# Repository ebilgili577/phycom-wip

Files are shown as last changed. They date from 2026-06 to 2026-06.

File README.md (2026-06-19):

# Reaction Game

Final game

A two-player reaction game built on an Adafruit Feather M4 Express.
A central NeoPixel ring flashes a colour and players race to press the matching
button before a time window closes. The window shrinks after every round.

## Game modes

On boot you land on a **mode-select** screen: the ring shows a constant colour for the selected game,
the **MODE** button cycles between games, and **START** confirms and launches.

### Game 1 — Reaction
The ring flashes a colour and each player races their own clock to hit the match.
Each player has 3 lives. The window shrinks each round; first to 0 lives loses.

### Game 2 — Duel
Turn-based sudden death. The active player's HP LEDs light to show whose turn it
is (randomized), and they must hit the colour shown on the ring. A correct press passes the
turn and shrinks the window; a wrong press **or** a timeout loses the game.

More game modes can be added.

## Controls

From either game-over screen: **START** replays the same game, **MODE** returns
to the mode selector.

## Hardware

- [Bills of material (BOM)](docs/bills_of_material.svg)
- [Schematic](docs/schematic.svg)
- [Parts to assemble](docs/parts_to_assemble.svg)
- [Laser-cut chassis](design/laser_cut.svg)
- [3D-printed button caps](design/Button_print.scad) (OpenSCAD)

## Assembly

1. Gather parts from the [BOM](docs/bills_of_material.svg).
2. Laser-cut the chassis from [design/laser_cut.svg](design/laser_cut.svg).
3. 3D-print ten button caps from [design/Button_print.scad](design/Button_print.scad).
4. Wire the board following the [schematic](docs/schematic.svg) and [parts](docs/parts_to_assemble.svg).
5. Mount buttons, buzzers, HP LEDs, and the NeoPixel ring into the chassis and solder connections.
6. Upload the game and test.
7. Have fun!

## Software setup

1. Install the [Arduino IDE](https://www.arduino.cc/en/software).
2. Add board support for **Adafruit Feather M4 Express** via the [Adafruit board package](https://learn.adafruit.com/add-boards-arduino-ide).
3. Install libraries through the Library Manager:
   - [Adafruit NeoPixel](https://github.com/adafruit/Adafruit_NeoPixel)
   - [Bounce2](https://github.com/thomasfredericks/Bounce2)
4. Open `reaction_game.ino`, select **Adafruit Feather M4 Express**, and upload.

## Gallery

| Stage | Photo |
| --- | --- |
| Cardboard form-factor sketch | Cardboard prototype |
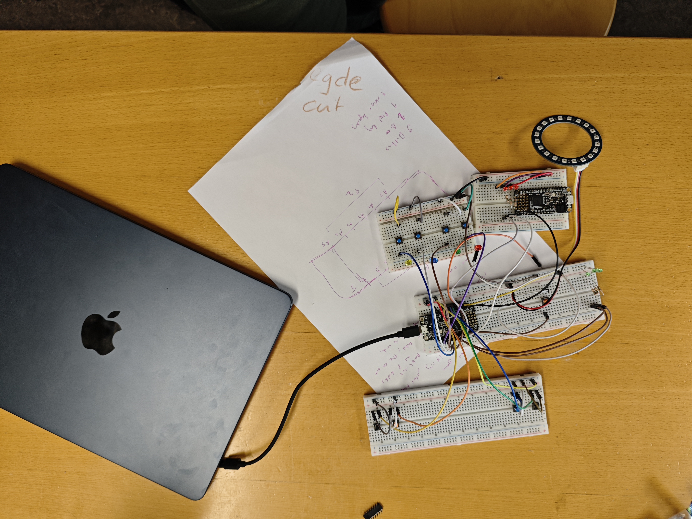
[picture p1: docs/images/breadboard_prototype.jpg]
Breadboard prototype
| Breadboard prototype |  |
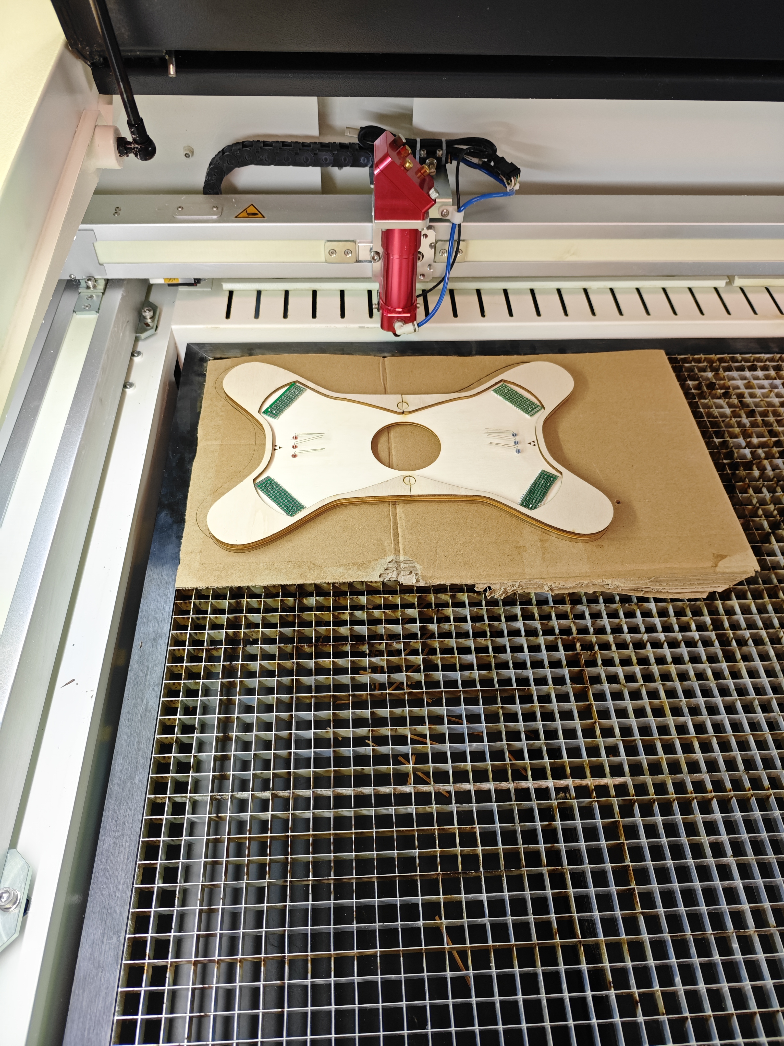
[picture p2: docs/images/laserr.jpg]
Laser cutting
| Laser-cutting the chassis |  |
| Final game | Final game |

## License

Licensed under the [MIT License](LICENSE).

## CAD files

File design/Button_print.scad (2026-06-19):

$fn = 36;
button_r = 3.35/2;

hole_r = 10/2;
h = 4;
little_h = 3;

button_travel = 0.3;

button_extra = 0.1;

hole_extra = 3/2;


// white one, good
module button_cover() {
    difference() {
    
        // hole
        cylinder(h=h+button_travel, r=hole_r+hole_extra);
        // button
        #cylinder(h=little_h-0.2, r=button_r+button_extra);
    }

}

module main() {

    button_cover();
    
}

main();

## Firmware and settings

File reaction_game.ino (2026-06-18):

#include <Adafruit_NeoPixel.h>
#include <Bounce2.h>


// ---- pins -------------------------------------------------------------------
#define PIXEL_PIN    A5 // LED ring connection
#define PIXEL_COUNT  20 // how many pixels on LED ring to light up

// player 1 colour buttons
#define P1_RED      12
#define P1_GREEN    11
#define P1_BLUE     10
#define P1_YELLOW   9

// player 2 colour buttons
#define P2_RED       A0
#define P2_GREEN     A1
#define P2_BLUE      A2
#define P2_YELLOW    A3

// buzzers
#define P1_BUZZER    6
#define P2_BUZZER    A4

#define START_BTN      22 // SCL
#define GAME_MODE_BTN  5    

#define READY_TIMER 50       // colorWipe step (ms). 

// ---- tuning -----------------------------------------------------------------
const int           START_LIVES  = 3;
const unsigned long START_WINDOW = 5000;   // ms for the first round
const float         SPEEDUP      = 0.75;   // window *= this each round
const unsigned long MIN_WINDOW   = 500;    // floor so it never becomes impossible
const uint8_t       BRIGHTNESS   = 60;    // 0-255

// ---- colours ----------------------------------------------------------------
enum Colour { RED = 0, GREEN = 1, BLUE = 2, YELLOW = 3 };

// ---- which game --------------------------------------------------------------
enum GameType { GAME_REACTION = 0, GAME_DUEL = 1, GAME_COUNT = 2 };
uint8_t selectedGame = GAME_REACTION;

// LED ring
Adafruit_NeoPixel strip(PIXEL_COUNT, PIXEL_PIN, NEO_GRB + NEO_KHZ800);

Bounce startBtn = Bounce();
Bounce modeBtn  = Bounce();
Bounce p1[4];   // Bouncer for player 1 buttons
Bounce p2[4];   // Bouncer player 2 buttons

// Player button pins
const uint8_t p1Pins[4]   = { P1_RED, P1_GREEN, P1_BLUE, P1_YELLOW };
const uint8_t p2Pins[4]   = { P2_RED, P2_GREEN, P2_BLUE, P2_YELLOW };

// HP LEDs
const uint8_t p1LedPins[3] = { 0, 1, 4 }; // RX, TX, D4
const uint8_t p2LedPins[3] = { 25, MOSI, MISO }; // SCK, MO, MI

// ---- game state -------------------------------------------------------------
enum Mode {
  MODE_SELECT,
  // game 1
  READY_SET_GO, SHOW_COLOR, WAITING, RESOLVE, GAME_OVER,
  // game 2
  G2_TURN, G2_WAIT, G2_OVER
};
Mode mode = MODE_SELECT;

// game 1
int  p1Lives = START_LIVES;
int  p2Lives = START_LIVES;
bool p1Resolved = false;
bool p2Resolved = false;

// game 2
int  activePlayer = 1;   // whose turn (1 or 2)
int  g2Loser      = 0;   // set when someone errs

// shared
uint8_t       target;                  // current target colour
unsigned long roundStart;              // millis() when the window opened
unsigned long window = START_WINDOW;   // current reaction window

bool seeded = false;                   // seed RNG on first human START press

// ============================================================================
//  setup / loop
// ============================================================================
void setup() {
  Serial.begin(115200);

  // Register buttons with input pullup
  for (uint8_t c = 0; c < 4; c++) {
    p1[c].attach(p1Pins[c], INPUT_PULLUP);
    p1[c].interval(15);
    p2[c].attach(p2Pins[c], INPUT_PULLUP);
    p2[c].interval(15);
  }

  // Register LEDs as output
  for (int i = 0; i < 3; i++) {
    pinMode(p1LedPins[i], OUTPUT);
    pinMode(p2LedPins[i], OUTPUT);
  }

  // Register buttons to bouncers
  startBtn.attach(START_BTN, INPUT_PULLUP);
  startBtn.interval(15);
  modeBtn.attach(GAME_MODE_BTN, INPUT_PULLUP);
  modeBtn.interval(15);

  // Configure LED ring
  strip.setBrightness(BRIGHTNESS);
  strip.begin();
  strip.show();  // Initialize all pixels to 'off'

  // Buzzer as output
  pinMode(P1_BUZZER, OUTPUT);
  pinMode(P2_BUZZER, OUTPUT);
}

void loop() {
  // poll EVERY button EVERY pass, in every mode
  startBtn.update();
  modeBtn.update();
  for (uint8_t c = 0; c < 4; c++) { p1[c].update(); p2[c].update(); }

  switch (mode) {
    case MODE_SELECT:  doModeSelect();  break;
    // game 1
    case READY_SET_GO: doReadySetGo();  break;
    case SHOW_COLOR:   doShowColor();   break;
    case WAITING:      doWaiting();     break;
    case RESOLVE:      doResolve();     break;
    case GAME_OVER:    doGameOver();    break;
    // game 2
    case G2_TURN:      doG2Turn();      break;
    case G2_WAIT:      doG2Wait();      break;
    case G2_OVER:      doG2Over();      break;
  }
}

// ============================================================================
//  mode select
// ============================================================================
void doModeSelect() {
  fillStrip(modeColour(selectedGame));   // constant colour = which game

  if (modeBtn.fell()) {
    selectedGame = (selectedGame + 1) % GAME_COUNT;
    Serial.print("Mode -> ");
    Serial.println(selectedGame == GAME_REACTION ? "Reaction (3 lives)" : "Duel (sudden death)");
  }

  if (startBtn.fell()) {
    if (!seeded) { randomSeed(micros()); seeded = true; }  // seed when player presses start
    if (selectedGame == GAME_REACTION) { startNewGame(); mode = READY_SET_GO; }
    else                               { startDuel();    mode = G2_TURN;      }
  }
}

uint32_t modeColour(uint8_t g) {
  switch (g) {
    case GAME_REACTION: return strip.Color(0, 127, 127);    // cyan
    case GAME_DUEL:     return strip.Color(255, 127, 0);    // orange
  }
  return 0;
}

// ============================================================================
//  GAME 1 -- reaction
// ============================================================================
void doReadySetGo() {
  colorWipe(strip.Color(127, 127, 127), READY_TIMER);
  mode = SHOW_COLOR;
}

void doShowColor() {
  target     = random(4); // randoimze; red, green, blue or yellow
  roundStart = millis(); // time it
  p1Resolved = false;
  p2Resolved = false;
  fillStrip(colourValue(target)); // dye the ring 

  Serial.print("Round - target ");  Serial.print(colourName(target));
  Serial.print(" | window ");       Serial.print(window);
  Serial.print("ms | P1 ");         Serial.print(p1Lives);
  Serial.print(" P2 ");             Serial.println(p2Lives);

  mode = WAITING; // wait for input
}

void doWaiting() {
  if (!p1Resolved) checkPlayer(p1, target, p1Resolved, p1Lives, 1);
  if (!p2Resolved) checkPlayer(p2, target, p2Resolved, p2Lives, 2);

  if (millis() - roundStart >= window) {
    if (!p1Resolved) { p1Lives--; soundWrong(P1_BUZZER); p1Resolved = true; Serial.println("P1 timeout -1"); }
    if (!p2Resolved) { p2Lives--; soundWrong(P2_BUZZER); p2Resolved = true; Serial.println("P2 timeout -1"); }
  }

  if (p1Resolved && p2Resolved) mode = RESOLVE;
}

void doResolve() {
  updateLives();

  if (p1Lives <= 0 || p2Lives <= 0) {
    announceWinner();
    if (p1Lives <= 0 && p2Lives <= 0) {
      soundLose(P1_BUZZER);                              //TODO: MAKE DRAW SOUND, maybe back and forth
    } else {
      int winnerPin = (p1Lives <= 0) ? P2_BUZZER : P1_BUZZER;
      int loserPin  = (p1Lives <= 0) ? P1_BUZZER : P2_BUZZER;
      soundWin(winnerPin);      // winner fanfare
      soundLose(loserPin);                         
    }
    mode = GAME_OVER;
    return;
  }
  // reduce window
  window = max((unsigned long)(window * SPEEDUP), (unsigned long)MIN_WINDOW);
  mode = READY_SET_GO;
}

void displayDraw() {
  fillStrip(strip.Color(127, 127, 127));  // draw, display white ring
}

void displayWinner(uint8_t player) { // light up side of player green
  colorWipeWinner(player);
}

void doGameOver() {
  if (p1Lives <= 0 && p2Lives <= 0) { displayDraw(); 
  } else  {
    uint8_t winner = (p1Lives == 0) ? 2 : 1; 
    displayWinner(winner);

  }

  if (startBtn.fell()) { startNewGame(); mode = READY_SET_GO; }  // replay
  if (modeBtn.fell())  { mode = MODE_SELECT; }                   // change game
}

// Resolve one player from their first relevant press this pass.
void checkPlayer(Bounce* btns, uint8_t tgt, bool &resolved, int &lives, int who) {
  int pin = (who == 1) ? P1_BUZZER : P2_BUZZER;
  if (btns[tgt].fell()) {              // correct colour
    resolved = true;
    soundCorrect(pin);
    Serial.print("P"); Serial.print(who); Serial.println(" correct");
    return;
  }
  for (uint8_t c = 0; c < 4; c++) {    // any wrong colour
    if (c != tgt && btns[c].fell()) {
      resolved = true;
      soundWrong(pin);
      lives--;
      Serial.print("P"); Serial.print(who); Serial.println(" WRONG -1");
      return;
    }
  }
}

void startNewGame() {
  p1Lives = START_LIVES;
  p2Lives = START_LIVES;
  window  = START_WINDOW;
  updateLives();
}

void announceWinner() {
  Serial.print("GAME OVER - ");
  if      (p1Lives <= 0 && p2Lives <= 0) Serial.println("draw!");
  else if (p1Lives <= 0)                 Serial.println("Player 2 wins!");
  else                                   Serial.println("Player 1 wins!");
}

// ============================================================================
//  GAME 2 -- duel (turn-based sudden death)
// ============================================================================
void startDuel() {
  window       = START_WINDOW;
  activePlayer = random(2) + 1;            // randomize
  g2Loser      = 0;
}

void doG2Turn() {
  target     = random(4);
  roundStart = millis();
  showTurnLeds(activePlayer);          // light the active side's HP LEDs
  fillStrip(colourValue(target));

  Serial.print("Duel - P");  Serial.print(activePlayer);
  Serial.print("'s turn, target "); Serial.print(colourName(target));
  Serial.print(" | window ");        Serial.print(window); Serial.println("ms");

  mode = G2_WAIT;
}

void doG2Wait() {
  Bounce* btns = (activePlayer == 1) ? p1 : p2;

  // correct -> pass the turn, speed up
  if (btns[target].fell()) {
    soundCorrect(activePlayer == 1 ? P1_BUZZER : P2_BUZZER);  
    Serial.print("P"); Serial.print(activePlayer); Serial.println(" correct");
    activePlayer = random(2) + 1;
    window = max((unsigned long)(window * SPEEDUP), (unsigned long)MIN_WINDOW);
    mode = G2_TURN;
    return;
  }

  // wrong colour -> lose
  for (uint8_t c = 0; c < 4; c++) {
    if (c != target && btns[c].fell()) {
      Serial.print("P"); Serial.print(activePlayer); Serial.println(" WRONG colour");
      duelLoss(activePlayer);
      return;
    }
  }

  // too slow -> counts as a mistake, lose
  if (millis() - roundStart >= window) {
    Serial.print("P"); Serial.print(activePlayer); Serial.println(" too slow");
    duelLoss(activePlayer);
  }
}

void duelLoss(int loser) {
  g2Loser = loser;
  int winner =  loser == 1 ? 2 : 1; // 1 or 2
  displayWinner(winner);
  soundWin(winner == 1 ? P1_BUZZER : P2_BUZZER);  
  soundLose(loser == 1 ? P1_BUZZER : P2_BUZZER);
  Serial.print("DUEL OVER - Player ");
  Serial.print(loser == 1 ? 2 : 1);
  Serial.println(" wins!");
  mode = G2_OVER;
}

void doG2Over() {
  // winner's HP LEDs stay lit as a victory marker
  showTurnLeds(g2Loser == 1 ? 2 : 1);

  if (startBtn.fell()) { startDuel(); mode = G2_TURN; }  // replay
  if (modeBtn.fell())  { mode = MODE_SELECT; }            // change game
}

// ============================================================================
//  shared helpers
// ============================================================================

// Ready set go display between rounds
void colorWipe(uint32_t c, uint8_t wait) {
  strip.clear(); 
  for (uint16_t i = 0; i < strip.numPixels(); i++) {
    strip.setPixelColor(i, c);
    strip.show();
    delay(wait);
  }
}

void colorWipeWinner(uint8_t player) { 
  strip.clear(); 
  for (uint16_t i = (player-1) * strip.numPixels()/2; i < strip.numPixels()/2 * player; i++) {
    strip.setPixelColor(i, strip.Color(0, 255, 0));
  }
  strip.show();

}

uint32_t colourValue(uint8_t c) {
  switch (c) {
    case RED:    return strip.Color(255, 0, 0);
    case GREEN:  return strip.Color(0, 255, 0);
    case BLUE:   return strip.Color(0, 0, 255);
    case YELLOW: return strip.Color(255, 255, 0);
  }
  return 0;
}

const char* colourName(uint8_t c) {
  switch (c) {
    case RED:    return "RED";
    case GREEN:  return "GREEN";
    case BLUE:   return "BLUE";
    case YELLOW: return "YELLOW";
  }
  return "?";
}

void fillStrip(uint32_t c) {
  for (uint16_t i = 0; i < strip.numPixels(); i++) strip.setPixelColor(i, c);
  strip.show();
}


// game 1: one LED per remaining life
void updateLives() {
  for (int i = 0; i < 3; i++) {
    digitalWrite(p1LedPins[i], i < p1Lives ? HIGH : LOW);
    digitalWrite(p2LedPins[i], i < p2Lives ? HIGH : LOW);
  }
}

// game 2: light all of one player's HP LEDs to show whose turn it is (0 = none)
void showTurnLeds(int who) {
  for (int i = 0; i < 3; i++) {
    digitalWrite(p1LedPins[i], who == 1 ? HIGH : LOW);
    digitalWrite(p2LedPins[i], who == 2 ? HIGH : LOW);
  }
}


// ---- game sounds ------------------------------------------------------------

void soundCorrect(int pin) {
  tone(pin, 988);  delay(80);   // B5
  tone(pin, 1319); delay(120);  // E6  -> rising "bleep-bloop"
  noTone(pin);
}

void soundWrong(int pin) {
  tone(pin, 220);  delay(150);  // A3
  tone(pin, 165);  delay(250);  // E3  -> descending "wah-wah"
  noTone(pin);
}


// "Sad trombone"
void soundLose(int pin) {
  tone(pin, 311); delay(320);   // Eb4
  tone(pin, 294); delay(320);   // D4
  tone(pin, 277); delay(320);   // Db4
  tone(pin, 262); delay(550);   // C4, held
  // final defeated slide downward
  for (int f = 262; f > 200; f -= 10) { tone(pin, f); delay(14); }
  tone(pin, 160); delay(400);
  noTone(pin);
}
// classic "da-da-da-DAAA ... da-DAAA"
void soundWin(int pin) {
  tone(pin, 784);  delay(160);  // G5
  tone(pin, 784);  delay(160);  // G5
  tone(pin, 784);  delay(160);  // G5
  tone(pin, 1047); delay(500);  // C6, big hold
  noTone(pin);     delay(120);  // breath
  tone(pin, 880);  delay(180);  // A5
  tone(pin, 1047); delay(180);  // C6
  tone(pin, 1319); delay(650);  // E6, triumphant final hold
  noTone(pin);
}

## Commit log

2026-06-18 feat: display green led on winners side and randomize turns in game 2
2026-06-18 feat: add sound effects on wrong/right button press and win/lose game
    [reaction_game.ino]
2026-06-19 chore: update schematics
2026-06-19 feat: add bom and parts to assemble
2026-06-19 feat: add 3d print for button cover
    [Button_print.scad]
